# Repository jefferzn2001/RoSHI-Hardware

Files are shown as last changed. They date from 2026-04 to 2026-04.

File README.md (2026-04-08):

# RoSHI Hardware

Hardware resources for the paper **RoSHI: A Versatile Robot-oriented Suit for Human Data In-the-Wild**.

<p align="center">
  
  &nbsp;
  
</p>

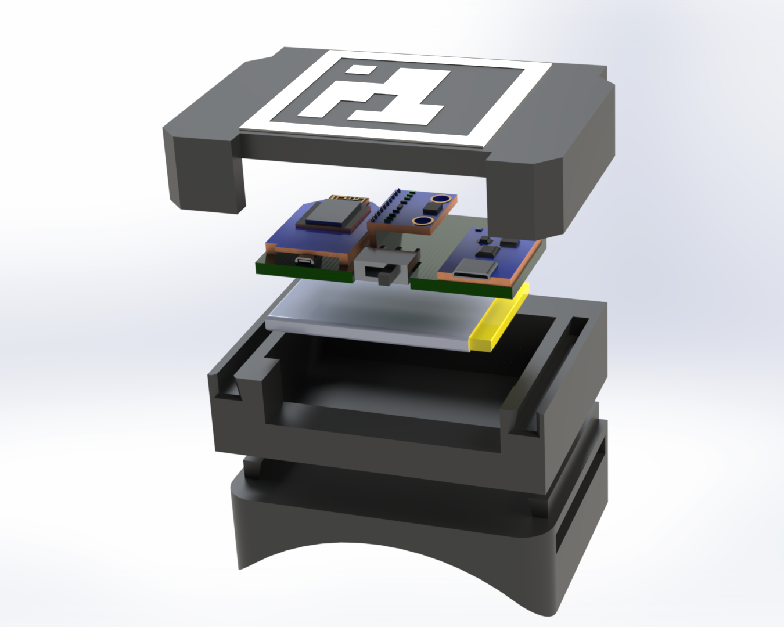
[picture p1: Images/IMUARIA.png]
RoSHI IMU tracker — exploded view


This repository contains the **3D-printed parts**, firmware, and helper scripts for building the nine wireless IMU trackers used in RoSHI.

## Repository layout

| Path | Contents |
|---|---|
| `3D Prints/` | STEP and STL models (receiver, IMU case, holder, and related parts) |
| `Firmware/IMU_Tracker/` | Tracker firmware (ESP8266 + BNO08x, ESP-NOW) |
| `Firmware/IMU_Receiver/HostRead/` | Host/receiver firmware (ESP32 + OLED) |
| `Firmware/python/` | `imu_reader.py`, `sample.py`, `visualize.py` — serial reader and examples |
| `Images/` | Figures such as the hardware render above |

## Python scripts

The scripts in `Firmware/python/` use only a few lightweight packages. Install them with:

```bash
pip install pyserial numpy matplotlib
```

From `Firmware/python/`, run e.g. `python sample.py` or `python visualize.py` with the ESP32 host connected over USB.

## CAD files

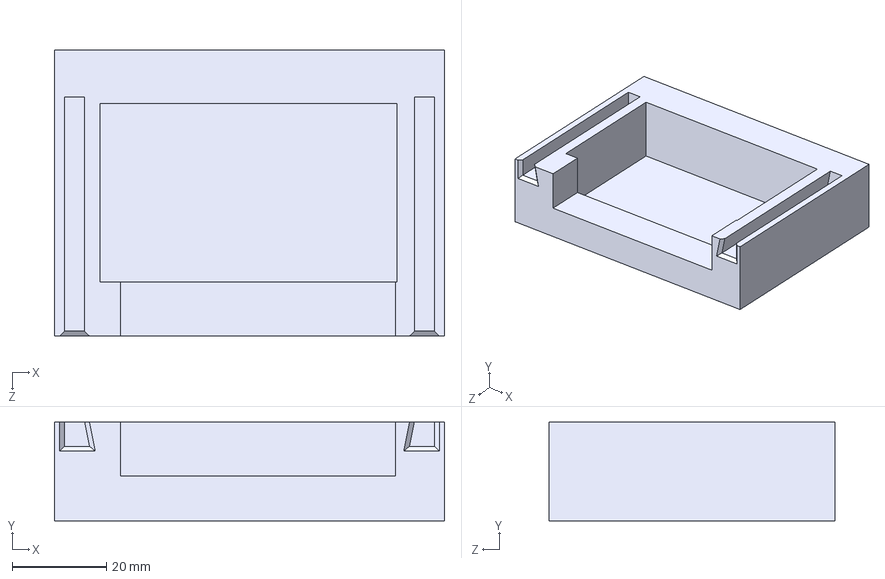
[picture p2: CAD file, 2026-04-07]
3D Prints/IMU_Case/Design/base.STEP
82.8 x 21.0 x 60.7 mm

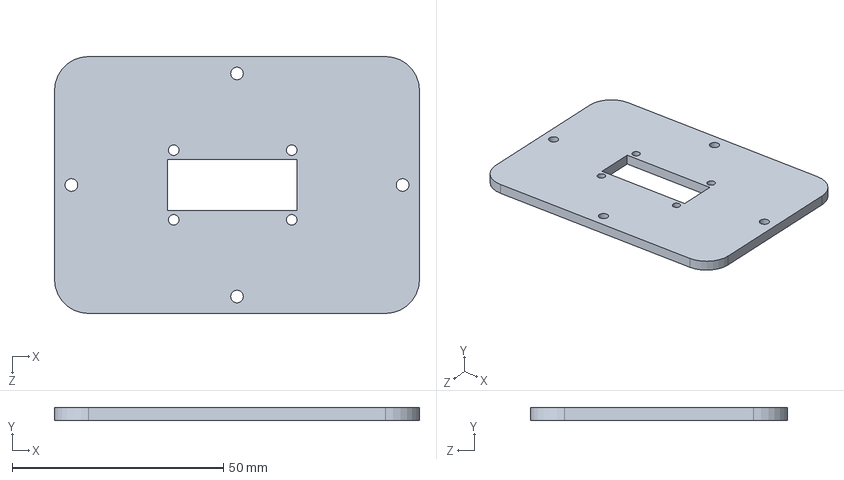
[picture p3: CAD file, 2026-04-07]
3D Prints/IMU_Holder/Design/hostcap.SLDPRT
86.4 x 3.00 x 60.8 mm

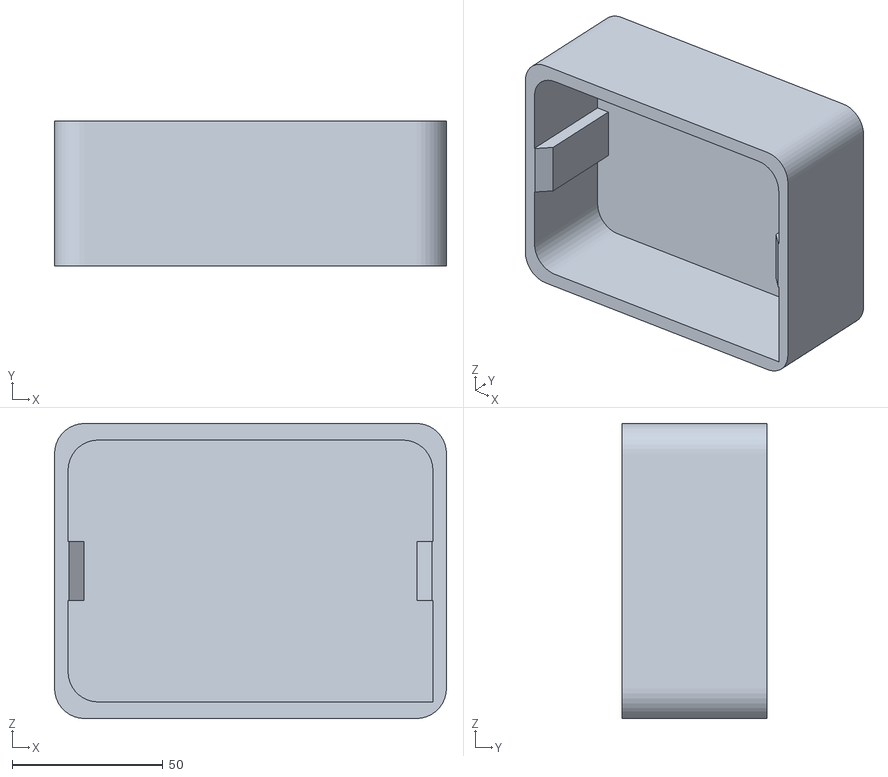
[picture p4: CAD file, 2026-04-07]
3D Prints/IMU_Holder/Print/cap.STL
130.0 x 48.0 x 97.9

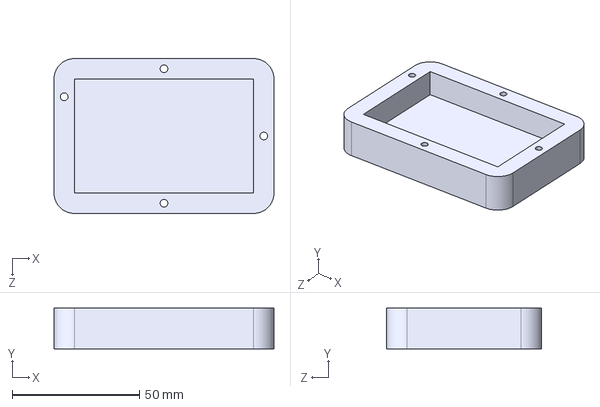
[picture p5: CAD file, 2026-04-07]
3D Prints/Receiver/Design/Receiver_Bottom.STEP
86.4 x 16.0 x 60.8 mm

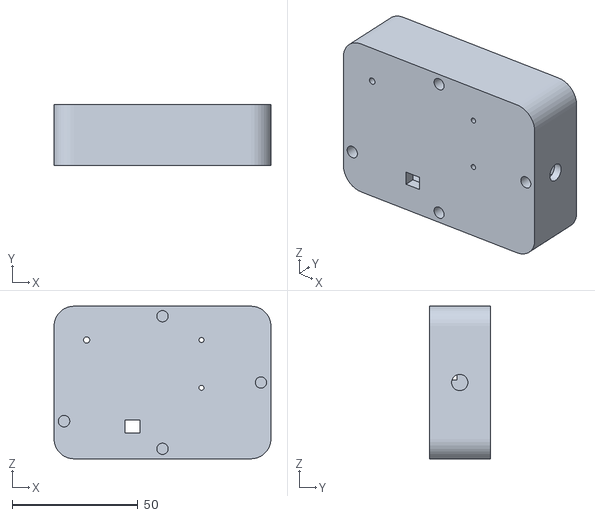
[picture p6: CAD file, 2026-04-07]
3D Prints/Receiver/Print/Receiver_Base.STL
86.4 x 24.2 x 60.8

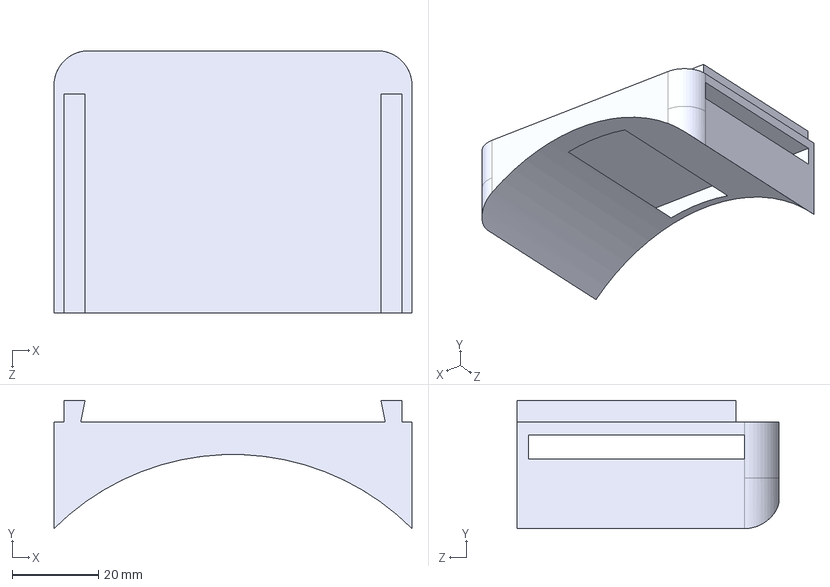
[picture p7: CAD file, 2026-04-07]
3D Prints/IMU_Case/Design/bot.STEP
82.8 x 29.7 x 60.7 mm

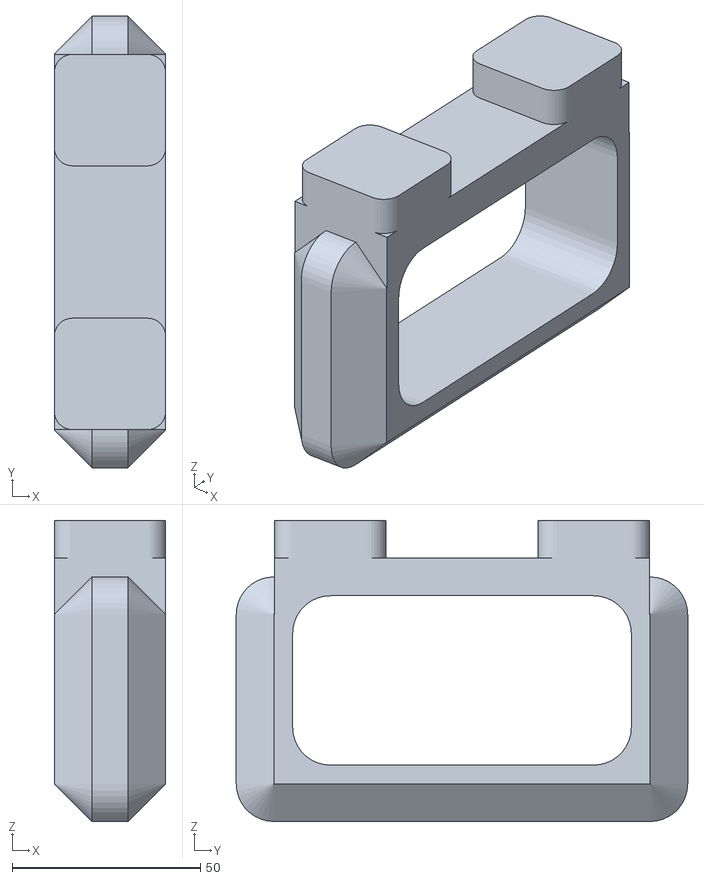
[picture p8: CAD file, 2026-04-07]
3D Prints/IMU_Holder/Print/handle.STL
29.6 x 120.0 x 80.0

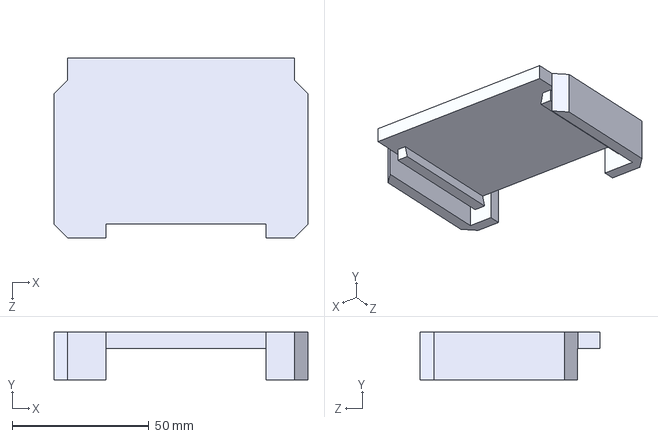
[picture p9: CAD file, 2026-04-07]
3D Prints/IMU_Case/Design/cap.STEP
92.8 x 17.5 x 65.7 mm

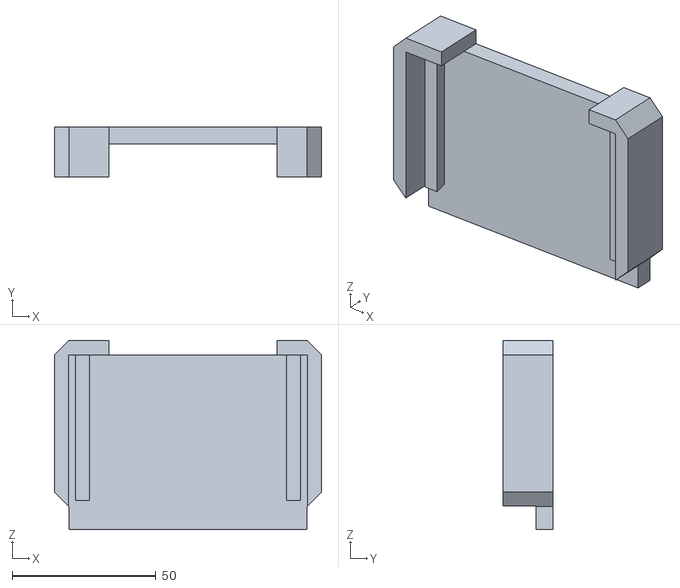
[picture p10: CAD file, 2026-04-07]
3D Prints/IMU_Case/Print/cap.STL
92.8 x 17.5 x 65.7

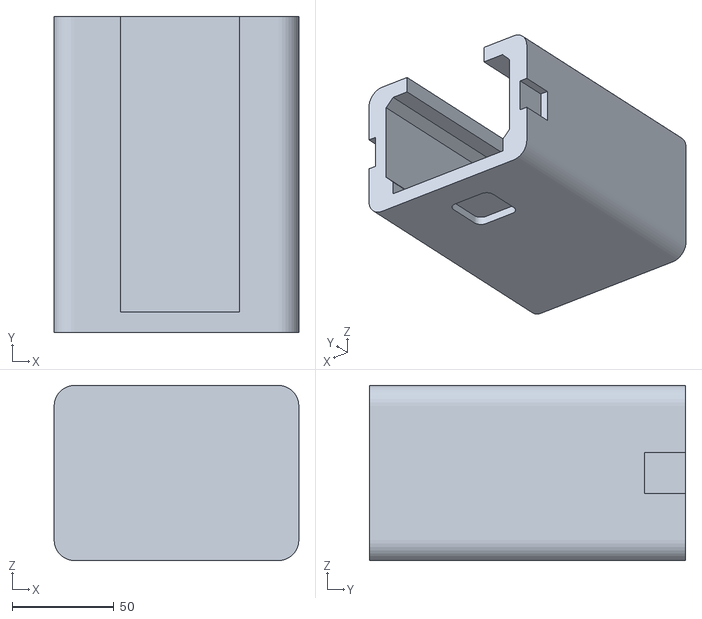
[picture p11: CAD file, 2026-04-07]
3D Prints/IMU_Holder/Print/bot.STL
120.0 x 154.9 x 85.8

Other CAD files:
3D Prints/IMU_Case/Print/base.STL
3D Prints/IMU_Case/Print/bot.STL
3D Prints/IMU_Holder/Design/cap.STEP
3D Prints/Receiver/Design/Receiver_Base.STEP
3D Prints/Receiver/Print/Receiver_Bot.STL
3D Prints/IMU_Holder/Design/hostbot.SLDPRT
3D Prints/Receiver/Design/Receiver_Cap.STEP
3D Prints/Receiver/Print/Receiver_Cap.STL
3D Prints/IMU_Holder/Design/bot.STEP
3D Prints/IMU_Holder/Design/handle.STEP
3D Prints/IMU_Holder/Design/hostcore.SLDPRT
3D Prints/IMU_Holder/Design/top.STEP
3D Prints/IMU_Holder/Print/top.STL

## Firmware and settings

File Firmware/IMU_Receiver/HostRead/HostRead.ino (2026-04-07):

#include <WiFi.h>
#include <esp_now.h>
#include <Wire.h>
#include <Adafruit_GFX.h>
#include <Adafruit_SSD1306.h>

/* ===== OLED setup ===== */
#define SCREEN_WIDTH 128
#define SCREEN_HEIGHT 64
#define OLED_RESET   -1
Adafruit_SSD1306 display(SCREEN_WIDTH, SCREEN_HEIGHT, &Wire, OLED_RESET);

/* ===== IMU packet (40 bytes) ===== */
typedef struct __attribute__((packed)) {
  uint8_t tracker_id;
  float   ax, ay, az;
  float   roll, pitch, yaw;
  float   qI, qJ, qK, qW;
  uint8_t battery_percent;
} IMUDataPacket;

/* ===== Button packet (4 bytes) ===== */
typedef struct __attribute__((packed)) { uint8_t id, batt, b14, b12; } ButtonPacket;

static inline bool looksLikeIMUPacket(int len){ return len == (int)sizeof(IMUDataPacket); }
static inline bool looksLikeButtonPacket(int len){ return len == (int)sizeof(ButtonPacket); }

/* ===== timing thresholds ===== */
static const uint32_t IMU_TIMEOUT_MS = 50;   // ~5 frames at 100Hz
static const uint32_t BTN_TIMEOUT_MS = 800;  // UX preference

/* ===== last-seen trackers (for screen) ===== */
static uint8_t lastBatt[10];
static uint32_t lastSeenMs[10];
static bool seen[10];

static uint8_t btn14 = 0, btn12 = 0;   // latest button raw (defaults 0)
static uint32_t lastBTNMs = 0;
static uint8_t lastPrintedBtnState = 255; // force first print

static inline uint8_t clamp2digits(uint8_t v){ return (v > 99) ? 99 : v; }

void drawGrid()
{
  display.clearDisplay();
  display.setTextColor(SSD1306_WHITE);

  // 5 columns, 2 rows; each cell ~25px wide, rows at y=8 and y=40
  const int startX[5] = { 0, 26, 52, 78, 104 };
  const int rowY[2]   = { 8, 40 };

  display.setTextSize(2);

  for (int idx = 0; idx < 10; ++idx) {
    int row = (idx < 5) ? 0 : 1;
    int col = (idx < 5) ? idx : (idx - 5);
    int x = startX[col];
    int y = rowY[row];

    if (idx == 0) {
      // Button state 0..2; revert to 0 after timeout; both-pressed maps to BTN14 (1)
      uint8_t state = 0;
      uint32_t ageB = millis() - lastBTNMs;
      if (ageB < BTN_TIMEOUT_MS) {
        if (btn14)      state = 1; // BTN14 pressed has priority
        else if (btn12) state = 2; // BTN12 pressed
      }
      display.setTextSize(1); display.setCursor(x, y - 7); display.print("0");
      display.setTextSize(2); display.setCursor(x, y); display.printf("%u", state);
      continue;
    }

    if (seen[idx] && (millis() - lastSeenMs[idx]) < IMU_TIMEOUT_MS) {
      uint8_t val = clamp2digits(lastBatt[idx]);
      display.setTextSize(1); display.setCursor(x, y - 7); display.print(idx);
      display.setTextSize(2); display.setCursor(x, y); display.printf("%u", val);
    }
  }

  display.display();
}

void onReceive(const esp_now_recv_info *, const uint8_t *data, int len)
{
  if (looksLikeIMUPacket(len)) {
    IMUDataPacket p; memcpy(&p, data, sizeof(p));
    Serial.printf(
      "ID:%d | r:%.1f p:%.1f y:%.1f | "
      "ax:%.2f ay:%.2f az:%.2f | "
      "qI:%.3f qJ:%.3f qK:%.3f qW:%.3f | "
      "batt:%u%%\n",
      p.tracker_id,
      p.roll, p.pitch, p.yaw,
      p.ax, p.ay, p.az,
      p.qI,  p.qJ,  p.qK,  p.qW,
      p.battery_percent);

    if (p.tracker_id < 10) {
      lastBatt[p.tracker_id] = p.battery_percent;
      lastSeenMs[p.tracker_id] = millis();
      seen[p.tracker_id] = true;
    }
    return;
  }

  if (looksLikeButtonPacket(len)) {
    ButtonPacket b; memcpy(&b, data, sizeof(b));
    // Update cached state/time
    btn14 = b.b14; btn12 = b.b12; lastBTNMs = millis();
    seen[0] = true; lastSeenMs[0] = lastBTNMs;
    // Mapped state (no state 3). Print all non-zero states; print 0 only once on timeout from loop.
    uint8_t state = 0;
    if (btn14)      state = 1;
    else if (btn12) state = 2;
    if (state != 0) {
      Serial.printf("BTN ID:%u | BTN14:%u BTN12:%u\n", b.id, b.b14, b.b12);
      lastPrintedBtnState = state;
    }
    return;
  }
}

void setup() {
  Serial.begin(115200); delay(300);

  memset(seen, 0, sizeof(seen));
  memset(lastBatt, 0, sizeof(lastBatt));
  memset(lastSeenMs, 0, sizeof(lastSeenMs));
  btn14 = 0; btn12 = 0; lastBTNMs = 0; lastPrintedBtnState = 255;

  Wire.begin();
  Wire.setClock(400000); // fast I2C for quicker refresh
  if (display.begin(SSD1306_SWITCHCAPVCC, 0x3C)) {
    display.clearDisplay();
    display.setTextSize(2);
    display.setTextColor(SSD1306_WHITE);
    display.setCursor(0, 0);
    display.println(F("Host"));
    display.display();
  }

  WiFi.mode(WIFI_STA); WiFi.begin();
  if (esp_now_init() != ESP_OK) { while (1); }
  esp_now_register_recv_cb(onReceive);
}

void loop() {
  static uint32_t lastDraw = 0;
  uint32_t now = millis();

  // If button state has timed out to 0 and we haven't printed 0 yet, print it once
  uint32_t ageB = now - lastBTNMs;
  if (ageB >= BTN_TIMEOUT_MS && lastPrintedBtnState != 0 && seen[0]) {
    Serial.printf("BTN ID:%u | BTN14:%u BTN12:%u\n", 0, 0, 0);
    lastPrintedBtnState = 0;
  }

  if (now - lastDraw >= 10) { // refresh ~100Hz
    lastDraw = now;
    drawGrid();
  }
}

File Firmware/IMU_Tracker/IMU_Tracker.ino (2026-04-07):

#include <ESP8266WiFi.h>
#include <espnow.h>
#include <Wire.h>
#include "SparkFun_BNO08x_Arduino_Library.h"

#define BNO_ADDR      0x4A
#define REPORT_US     10000      // 100 Hz
#define BAUDRATE      115200

const uint8_t TRACKER_ID = 9;    // set unique ID per node
uint8_t peerMAC[] = { 0x34, 0xCD, 0xB0, 0x34, 0x93, 0xE4 };

BNO08x imu;

/* ---- 40‑byte packet ---- */
typedef struct __attribute__((packed)) {
  uint8_t tracker_id;
  float   ax, ay, az;
  float   roll, pitch, yaw;
  float   qI, qJ, qK, qW;
  uint8_t battery_percent;
} IMUDataPacket;

IMUDataPacket pkt;

/* ---- battery helpers (factor 5.00) ---- */
const float ADC_TO_VBAT = 5.00f;

float rawToVoltage(uint16_t raw)
{
  return (raw / 1023.0f) * 1.0f * ADC_TO_VBAT;
}
uint8_t vToPercent(float v)
{
  v = constrain(v, 3.3f, 4.2f);
  return (uint8_t)(((v - 3.3f) / 0.9f) * 100.0f);
}

/* ---- setup ---- */
void setup() {
  Serial.begin(BAUDRATE);
  Wire.begin(); Wire.setClock(400000); delay(200);

  if (!imu.begin(BNO_ADDR, Wire)) { Serial.println("IMU fail"); while (1); }
  imu.enableRotationVector(REPORT_US);
  imu.enableAccelerometer(REPORT_US);

  WiFi.mode(WIFI_STA); WiFi.disconnect();
  if (esp_now_init() != 0) { Serial.println("ESP‑NOW fail"); while (1); }
  esp_now_set_self_role(ESP_NOW_ROLE_CONTROLLER);
  esp_now_add_peer(peerMAC, ESP_NOW_ROLE_SLAVE, 1, NULL, 0);

  Serial.println("Tracker: sending full quat + batt%");
}

/* ---- main loop ---- */
void loop() {
  if (!imu.getSensorEvent()) return;

  static float ax, ay, az, roll, pitch, yaw, qI, qJ, qK, qW;
  static uint8_t got = 0;

  switch (imu.getSensorEventID()) {
    case SENSOR_REPORTID_ROTATION_VECTOR:
      qI = imu.getQuatI(); qJ = imu.getQuatJ();
      qK = imu.getQuatK(); qW = imu.getQuatReal();
      roll  = imu.getRoll()  * 180.0f / PI;
      pitch = imu.getPitch() * 180.0f / PI;
      yaw   = imu.getYaw()   * 180.0f / PI;
      got |= 0b01; break;

    case SENSOR_REPORTID_ACCELEROMETER:
      ax = imu.getAccelX(); ay = imu.getAccelY(); az = imu.getAccelZ();
      got |= 0b10; break;
  }

  if (got == 0b11) {
    got = 0;

    uint16_t raw = analogRead(A0);
    float    v   = rawToVoltage(raw);
    uint8_t  batt= vToPercent(v);

    /* fill packet */
    pkt.tracker_id = TRACKER_ID;
    pkt.ax = ax; pkt.ay = ay; pkt.az = az;
    pkt.roll = roll; pkt.pitch = pitch; pkt.yaw = yaw;
    pkt.qI = qI; pkt.qJ = qJ; pkt.qK = qK; pkt.qW = qW;
    pkt.battery_percent = batt;

    esp_now_send(peerMAC, (uint8_t*)&pkt, sizeof(pkt));

    /* local debug (keeps raw for calibration) */
    Serial.printf("ID:%d raw:%u v:%.2f batt:%u%%\n",
                  TRACKER_ID, raw, v, batt);
  }
}

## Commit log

2026-04-07 Initial commit: RoSHI hardware, firmware, 3D prints, and README.
    Made-with: Cursor
    [Receiver_Base.STEP, Receiver_Base.STL, Receiver_Bot.STL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]
2026-04-07 README: caption hardware overview for IMUARIA exploded view.
    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
